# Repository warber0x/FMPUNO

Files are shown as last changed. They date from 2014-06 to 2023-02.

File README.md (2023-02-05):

# Finally FMPUNO Is now compatible with python3 :gift:
- Nickname in arduino forum: BlackSharp (to search through the arduino forum discussion)
- Date of the first release: 12/24/2013.
- Date of last release: 24/11/2021
- Date Github publish: 06/05/2014.
- Video link: https://www.youtube.com/watch?v=Dh3tBewMzdY

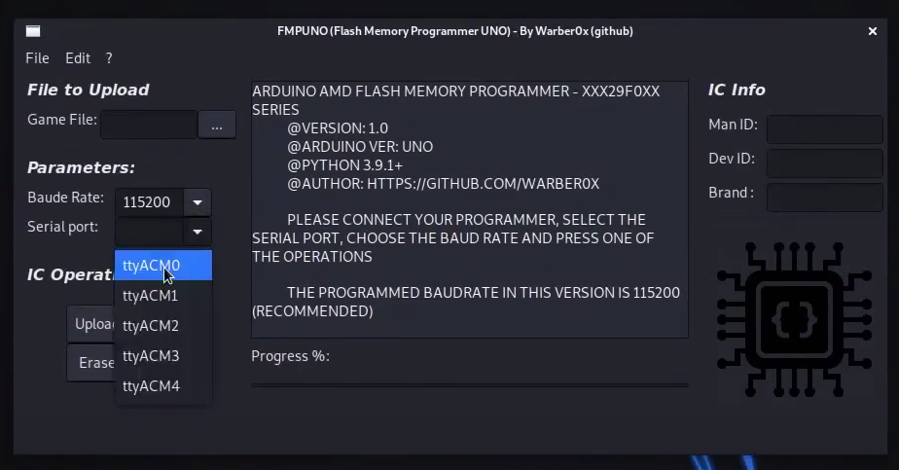
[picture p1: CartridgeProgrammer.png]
Cartridge Programmer


After so many years, I wanted to bring to life this project that I made before and make it more stable especially the GUI app. Now, the application is more stable and works like a charm.

**IMPORTANT NOTICE: The diagram wiring image has an issue**
* PIN 32 -> VCC
* PIN 16 -> Ground

## Introduction:
This project is a Flash memory programmer based on Arduino UNO.

The main reason for creating this project is to be able to program a flash memory, put it in gameboy cartidge and play any game you want. The commercial programmer is expensive and creating your own is fun ...

In this repo you'll find the graphic scheme of the project in JPEG format as well as in Fritzing format.

If you wan to build this, it's not difficult. Just respect the wiring and everything will be okay. 

The diagram is not perfect I know but it helps ... Maybe one day I will make it better :zzz:

Some resistors are not added in the diagram. Therefore, don't forget to add resistor for every input especially for Adresses and Data chip pins, the same for arduino and the shift registers (The floating state values is the main problem if it doesn't work). All of the resistors in the project are in 10Kohms.

You must have a gameboy cartidge that has a flash instead of ROM chip

Adding to this, I have programmed a Python GUI software to make a chip programming more easier. The supported chips are:

- Amic A29040.
- AMD AM29F040.
- AMD AM29F010.

The GUI app works with python3. It crashes sometimes when the upload is finished. You are free to increase or customize the code (But keep my name plz).

## REQUIREMENTS: 💾
- Computer with linux/Windows 7. Linux is recommanded (I was testing on KALI)
- Tested with python3 (There were major bugs in python2)
- Wxpython library (pip3 install wxpython)
- Pubsub lib 
- Arduino IDE with the Flash_memory_programmer Sketch.
- Circuit, Diagram ... you know what I mean :wink:
- Chip AM29F010-40, A29010-40

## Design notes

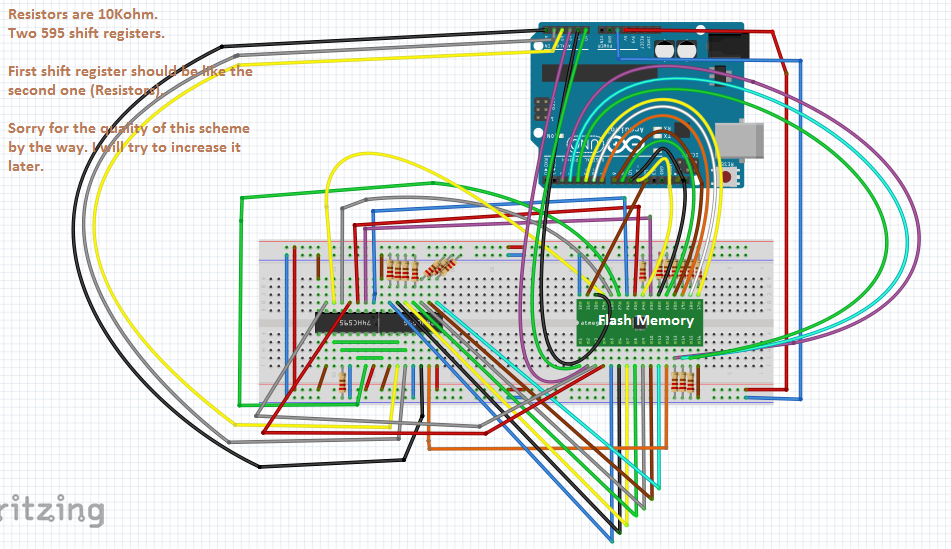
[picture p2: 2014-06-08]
Schemes/Scheme Flash Memory Programmer.png

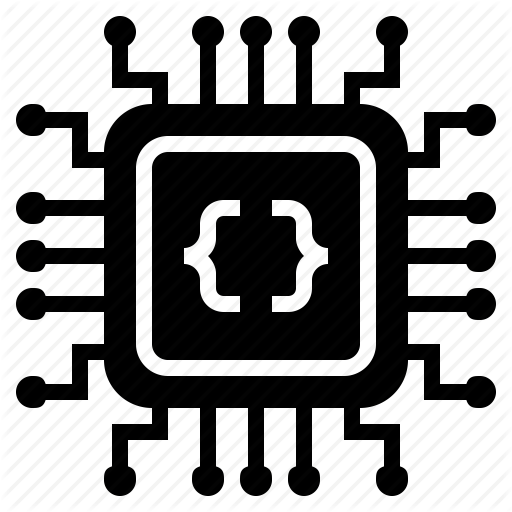
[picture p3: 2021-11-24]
GUI_python3/avr.png

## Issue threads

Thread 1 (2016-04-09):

Wire on pin 16 going into ground, not vcc

bogger33, 2016-04-09:
Hey, thanks for the project!

The wiring diagram has a mistake in it, the wire from pin 16 of the chip is red, but goes into ground on the diagram, and so does the one on pin 32 (which is blue). Pin 32 should go to vcc

warber0x, 2016-04-11:
Thanks dude. Good looking out.

Closed 2018-01-28.

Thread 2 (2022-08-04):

Issue with running the python GUI

gufunkt-tacos, 2022-08-04:
Whenever I try to run the code it outputs this error.

`C:\Users\Administrator\Downloads\FMPUNO-master\FMPUNO-master\GUI_python3>python FlashMemoryProgrammer_GUI.py
Traceback (most recent call last):
  File "C:\Users\Administrator\Downloads\FMPUNO-master\FMPUNO-master\GUI_python3\FlashMemoryProgrammer_GUI.py", line 852, in <module>
    thread1 = starter(1, 'Thread-1', 1)
  File "C:\Users\Administrator\Downloads\FMPUNO-master\FMPUNO-master\GUI_python3\FlashMemoryProgrammer_GUI.py", line 840, in __init__
    frame = programmer_gui(parent=None, id=-1)
  File "C:\Users\Administrator\Downloads\FMPUNO-master\FMPUNO-master\GUI_python3\FlashMemoryProgrammer_GUI.py", line 93, in __init__
    font3 = wx.Font(12, wx.NORMAL, wx.ITALIC, wx.BOLD)
wx._core.wxAssertionError: C++ assertion ""ff_family != (0<<4)"" failed at ..\..\src\msw\font.cpp(624) in wxNativeFontInfo::SetFamily(): unknown wxFontFamily`

I've installed PubSub and wxPython. My python version is 3.9.1 and I have the same error with 3.9.13.

TheR3d0ne, 2022-08-04:
@gufunkt-tacos check this out [https://stackoverflow.com/questions/5278884/fonts-problem-when-switching-from-wxpython-2-8-to-2-9](https://stackoverflow.com/questions/5278884/fonts-problem-when-switching-from-wxpython-2-8-to-2-9). It's
 a wxPython version problem. Otherwise, you can modify the code to be aligned with your version.

Closed 2022-08-07.

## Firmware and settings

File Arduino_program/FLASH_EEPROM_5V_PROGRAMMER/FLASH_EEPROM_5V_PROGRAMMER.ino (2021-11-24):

/* @Author: Radouane SAMIR
   @Version: 0.1
   @Chip version: AM29F010 A29040
   
   This code is tested on AM29F010.
   
   For AM29F040B the command sequence are little bit different:
   0x555 rather than 0x5555 see the datasheet. But the timing is the same
   
   You are free to modify the code as you want, but please keep my name as is.
*/

#include <avr/io.h>
#include <util/delay.h>

/* Flash SIZE, used only in read operation*/
#define FLASHSIZE 131072 

uint32_t address = 0;
uint32_t gameSize = 0;

char buffer[20] = {0};
char cmd = 0;
int  index = 0;
char tab[10] = {0};

/* Need a fast change mode IN/OUT */

void flash_change_pins_mode(boolean io)
{
  if (io) {
    DDRD &= ~(1<<2);
    DDRD &= ~(1<<3);
    DDRD &= ~(1<<4);
    DDRD &= ~(1<<5);
    DDRD &= ~(1<<6);
    DDRD &= ~(1<<7);
    DDRB &= ~(1<<0);
    DDRB &= ~(1<<1);
  }
  else
  {
    DDRD |= (1<<2);
    DDRD |= (1<<3);
    DDRD |= (1<<4);
    DDRD |= (1<<5);
    DDRD |= (1<<6);
    DDRD |= (1<<7);
    DDRB |= (1<<0);
    DDRB |= (1<<1);
  }
}

void flash_ctrl_deselect()
{
  digitalWrite(10, HIGH);  //CE
  digitalWrite(12, HIGH);  //WE
  digitalWrite(11, HIGH);  //OE
}

void flash_ctrl_rd()
{
  digitalWrite(11, LOW);
  _delay_us(1);
  digitalWrite(10, LOW);
  _delay_us(1);
}

void flash_ctrl_wr()
{
  digitalWrite(10, LOW);
  _delay_us(1);
  digitalWrite(12, LOW);
  _delay_us(1);
}  

/**************************************************
   Function to access to 
   the highest addresses in the chip 
   Highest 16bits is given to the function
   and do a bit manipulation to set pins High/Low
***************************************************/

void flash_set_highest_addresses(uint16_t addr)
{ 
  /* Highest addresses */
  
  if (addr&bit(0))
  PORTC |= _BV(PORTC2);
  else
  PORTC &= ~_BV(PORTC2);
  
  if (addr&bit(1))
  PORTC |= _BV(PORTC1);
  else
  PORTC &= ~_BV(PORTC1);
  
  if (addr&bit(2))
  PORTC |= _BV(PORTC0);
  else
  PORTC &= ~_BV(PORTC0);
}

/****
 * Shift registers manipulation
 *******************************/

void flash_enable_latch()
{
  /* Shift register Latch */
  digitalWrite(A4, HIGH); 
}

void flash_disable_latch()
{
  /* Shift register Latch */
  digitalWrite(A4, LOW);
}

void flash_enable_serial_clock()
{
  /* Shift register Serial clock */
  digitalWrite(A3, HIGH);
}

void flash_disable_serial_clock()
{
  digitalWrite(A3, LOW);
}

/** 
 * Calculated the given address
 * shift register manipulation
 **************************************/ 

void flash_send_serial_data(uint16_t data)
{ 
  /* Shift register manipulation */
  /* Respect the wiring */
  
  uint16_t addr = 0;
  byte octect1 = 0; 
  byte octect2 = 0;
  
  addr = (data<<8);
  octect1 = (addr>>8);
  
  addr = (data>>8);
  octect2 = addr;
  
  flash_disable_latch();
  for (int i=7;i>=0; i--)
  {
    flash_disable_serial_clock();
    if (octect2&(1<<i))
    PORTC |= _BV(PORTC5);
    else
    PORTC &= ~_BV(PORTC5);
    flash_enable_serial_clock();
  }
  
  
  for (int i=7;i>=0; i--)
  {
    flash_disable_serial_clock();
    if (octect1&(1<<i))
    PORTC |= _BV(PORTC5);
    else
    PORTC &= ~_BV(PORTC5);
    flash_enable_serial_clock();
  }
  flash_enable_latch();
}

/**
 * Set the address *
 *******************/

void flash_addr_set(uint32_t addr)
{
  /* Send address  to the shift register  */
  
  uint16_t LSB;
  uint16_t MSB;
  
  LSB = addr;
  MSB = (addr>>16);
  
  flash_send_serial_data(LSB);
  flash_set_highest_addresses(MSB);
}

/**
 * Calculate the data given and set change pins state
 *****************************************************/

void flash_data_set(uint8_t data)
{
  uint8_t temp;
  uint8_t temp2;
  
  temp = (data<<2);
  temp2 = (data>>6);
  
  for (int i = 2; i < 8; i++)
  {
    if (temp&bit(i))
    {
      DDRD |= (1<<i);
      PORTD |= (1<<i);
    }
    else
    {
      PORTD &= ~(1<<i);
      DDRD &= ~(1<<i);  
    }
   
  }
  
  if(temp2&(1<<0)) 
  {
    DDRB |= _BV(PORTB0);
    PORTB |= _BV(PORTB0);
  }
  else
  {
    PORTB &= ~_BV(PORTB0);
    DDRB &= ~(1<<0);
  }
  
  if(temp2&(1<<1))
  {
    DDRB |= _BV(PORTB1);
    PORTB |= _BV(PORTB1);
  }
  else
  {
    PORTB &= ~_BV(PORTB1);
    DDRB &= ~_BV(PORTB1);
  }
}

/** 
 * Get Data from the chip *
 * MIND: the pull-down resistors
 *********************************/

byte flash_data_get()
{
  /* get data from data bus */
  
  byte data = 0;
  boolean state = LOW;
  boolean state2 = LOW;
  
  for (int i = 2, j = 0; i <= 9; i++, j++)
  {
        state = digitalRead(i);  
        state2 = digitalRead(i); 
        if (state == state2)
           if (state == HIGH)
           bitWrite(data, j, HIGH); 
           
  }
  return data;
}

/*
 * Data polling in programming operation
 *****************************************/

boolean flash_DQ7_byte_poll(uint32_t addr, byte data)
{
  byte octect = 0;
  flash_change_pins_mode(1);
  flash_addr_set(addr);
  flash_ctrl_rd();
  octect = (flash_data_get()>>7);
  while (octect!=(data>>7));
  flash_ctrl_deselect();
  return true;
}

boolean flash_DQ7_erase_poll()
{
  byte octect = 0;
  flash_change_pins_mode(1);
  octect = (flash_data_get()>>7);
  
  while (octect!=1)
  octect = (flash_data_get()>>7);
  
  if (octect)
  Serial.println("Erasure complete");
  
  flash_ctrl_deselect();
  return true;
}

/****
 * Set command sequence and send it to the chip
 ***********************************************/

void flash_send_command(uint32_t addr, uint8_t data)
{
  /* Send command sequence */
  
  flash_addr_set(addr);
  delayMicroseconds(1);
  flash_ctrl_wr();

  flash_data_set(data);
  delayMicroseconds(1);
}

/****
 * Autoselect mode to get info from the chip
 * It's useful to test the chip before any operation
 ******************************************************/

void flash_device_id()
{
  /* This is used to get code identification 
   * from the chip in autoselect mode
   * See the datasheet
   ******************************************/
  
  flash_ctrl_deselect();
  
  //digitalWrite(11, HIGH);
  
  delay(1000);
  
  flash_change_pins_mode(0);
  
  flash_send_command(0x5555, 0xAA);
  flash_ctrl_deselect();
  
  
  flash_send_command(0x2AAA, 0x55);
  flash_ctrl_deselect();
  
  flash_send_command(0x5555, 0x90);
  flash_ctrl_deselect();
 
  delay(1000);
  
  flash_change_pins_mode(1);

  flash_addr_set(0x01);
  delay(1);
  flash_ctrl_rd();
  
  Serial.print(flash_data_get(), HEX);
  //Serial.print("Get device ID complete, Please wait restarting the chip ... ");
  delay(1);
  flash_reset_chip();
  //Serial.println("Done.");
  delay(1000);
  flash_ctrl_deselect();
}

/** AM29F040 **/
/***************/

void flash_get_id_40()
{
  /* This is used to get code identification 
   * from the chip in autoselect mode
   * See the datasheet
   ******************************************/
   
  byte data = 0x00;
  
  flash_ctrl_deselect();
  
  //digitalWrite(11, HIGH);
  
  delay(1000);
  
  flash_change_pins_mode(0);
  
  flash_send_command(0x555, 0xAA);
  flash_ctrl_deselect();
  
  flash_send_command(0x2AA, 0x55);
  flash_ctrl_deselect();
  
  flash_send_command(0x555, 0x90);
  flash_ctrl_deselect();
 
  delay(1000);
  
  flash_change_pins_mode(1);

  flash_addr_set(0x00);
  flash_ctrl_rd();
  
  data = flash_data_get();
  
  if (data < 0x0A) 
  Serial.print("0");
  
  Serial.print(data, HEX);
  
  flash_ctrl_deselect();
  
  flash_reset_chip();
  delay(1000);
}


void flash_get_id()
{
  /* This is used to get code identification 
   * from the chip in autoselect mode
   * See the datasheet
   ******************************************/
   
  byte data = 0x00;
  
  flash_ctrl_deselect();
  
  //digitalWrite(11, HIGH);
  
  delay(1000);
  
  flash_change_pins_mode(0);
  
  flash_send_command(0x5555, 0xAA);
  flash_ctrl_deselect();
  
  flash_send_command(0x2AAA, 0x55);
  flash_ctrl_deselect();
  
  flash_send_command(0x5555, 0x90);
  flash_ctrl_deselect();
 
  delay(1000);
  
  flash_change_pins_mode(1);
  
  flash_addr_set(0x00);
  flash_ctrl_rd();
  
  data = flash_data_get();
  
  if (data < 0x0A) 
  Serial.print("0");
  
  Serial.print(data, HEX);
  
  flash_ctrl_deselect();
  
  flash_reset_chip();
  delay(1000);
}

void flash_read_memory(uint32_t addr)
{
  /* Read the chip until the address given */  
  int c = 0;
  
  flash_change_pins_mode(1);
  
  for (uint32_t i = 0; i < addr; i++)
  {
    flash_ctrl_deselect();
    
    flash_addr_set(i);
    
    flash_ctrl_rd();
    
    Serial.print(flash_data_get(),HEX); 
    flash_ctrl_deselect();
  }
}

/* This is the sequence to program a byte on the memory *
 * 0x5555 0x2AAA is for AM29F010
 * 0x555 0x2AA is for AM29F040 A29F040
 ********************************************************/

boolean flash_program_byte(uint32_t addr, uint8_t data)
{
  flash_ctrl_deselect();
  
  flash_send_command(0x5555, 0xAA); 
  flash_ctrl_deselect();
  
  flash_send_command(0x2AAA, 0x55);
  flash_ctrl_deselect();
  
  flash_send_command(0x5555, 0xA0);
  flash_ctrl_deselect();
  
  //Program Address & Program data
  flash_send_command(addr, data);
  flash_ctrl_deselect();
  
  /** Data Polling **/
  while (!flash_DQ7_byte_poll(addr, data));
  
  return true;
}

/* This is the sequence to program a byte on the memory *
 * 0x5555 0x2AAA is for AM29F010
 * 0x555 0x2AA is for AM29F040 A29F040
 ********************************************************/

void flash_reset_chip()
{
  /* This is reset command for the AM29F010 */
  
  flash_ctrl_deselect();
  
  flash_send_command(0x5555, 0xAA);
  flash_ctrl_deselect();
  
  flash_send_command(0x2AAA, 0x55);
  flash_ctrl_deselect();
  
  flash_send_command(0x5555, 0xF0);
  flash_ctrl_deselect();
  
  delay(1000);
}

/* This is the sequence to program a byte on the memory *
 * 0x5555 0x2AAA is for AM29F010
 * 0x555 0x2AA is for AM29F040 A29F040
 ********************************************************/

void flash_erase_memory()
{
  flash_ctrl_deselect();
  delay(1000);
  
  //flash_change_pins_mode(0);
  
  flash_send_command(0x5555, 0xAA);
  flash_ctrl_deselect();
  
  flash_send_command(0x2AAA, 0x55);
  flash_ctrl_deselect();
  
  flash_send_command(0x5555, 0x80);
  flash_ctrl_deselect();
  
  flash_send_command(0x5555, 0xAA);
  flash_ctrl_deselect();
  
  flash_send_command(0x2AAA, 0x55);
  flash_ctrl_deselect();
  
  flash_send_command(0x5555, 0x10);
  flash_ctrl_deselect();
  
  _delay_ms(1000);
  //flash_DQ7_erase_poll();
  flash_reset_chip();
  Serial.print("Erasure Complete");
}

/* To erase AM29F040 */
/*********************/

void flash_erase_memory2()
{
  flash_ctrl_deselect();
  delay(1000);
  
  //flash_change_pins_mode(0);
  
  flash_send_command(0x555, 0xAA);
  flash_ctrl_deselect();
  
  flash_send_command(0x2AA, 0x55);
  flash_ctrl_deselect();
  
  flash_send_command(0x555, 0x80);
  flash_ctrl_deselect();
  
  flash_send_command(0x555, 0xAA);
  flash_ctrl_deselect();
  
  flash_send_command(0x2AA, 0x55);
  flash_ctrl_deselect();
  
  flash_send_command(0x555, 0x10);
  flash_ctrl_deselect();
  
  _delay_ms(1000);
  //flash_DQ7_erase_poll();
  //flash_reset_chip();
  Serial.print("Erasure Complete");
}

/*
 * Read data coming from the computer's USB port *
 *************************************************/

void receiveDataFromPC()
{
  if (Serial.available()>0)
  {
    uint8_t data = Serial.read();
    flash_program_byte(address++, data); 
  }
}

/* Intiate the programing when the python GUI send a trigger */
/*************************************************************/

void startProgramming()
{
    flash_change_pins_mode(0);
    
    Serial.print("+");
    while (!Serial.available());
    while (Serial.available() > 0)
    {
      char car = Serial.read();
      delay(10);
      tab[index++]=car;
      
    }
    tab[index] = '\0';
    
    Serial.print("+");
    
    while(address <= atol(tab)) {
    receiveDataFromPC();
    }
}

void setup()
{
  Serial.begin(115200);
  //ANALOG_CONFIG;
  
  int c = 0;
 
  //Set the shift register pins
  
  pinMode(A5, OUTPUT);
  pinMode(A4, OUTPUT);
  pinMode(A3, OUTPUT);
  
  //set the highest address pins
  
  pinMode(A2, OUTPUT);
  pinMode(A1, OUTPUT);
  pinMode(A0, OUTPUT);
  
  //Set the chip controller
  
  pinMode(10, OUTPUT);
  pinMode(11, OUTPUT);
  pinMode(12, OUTPUT);
  
  //Set data pin mode
  pinMode(2, OUTPUT);
  pinMode(3, OUTPUT);
  pinMode(4, OUTPUT);
  pinMode(5, OUTPUT);
  pinMode(6, OUTPUT);
  pinMode(7, OUTPUT);
  pinMode(8, OUTPUT);
  pinMode(9, OUTPUT);
  
  delay(1000);
  
  address = 0;
  
  flash_ctrl_deselect();
}

void loop()
{ 
  while (!Serial.available());
  cmd = Serial.read();
  
  switch(cmd)
  {
    case 'R':
    flash_read_memory(0xFF);
    Serial.println("");
    break;
    
    case 'E':
    flash_erase_memory();
    Serial.println("");
    break;
    
    case 'W':
    startProgramming();
    Serial.println("");
    break;
    
    case 'I':
    flash_get_id();
    Serial.println("");
    break;
    
    case 'D':
    flash_device_id();
    Serial.println("");
    break;
  
    default:
    cmd = 0;
  }
  cmd = 0;
  index = 0;
  memset(tab, '\0', sizeof(tab));
  delay(10);
}

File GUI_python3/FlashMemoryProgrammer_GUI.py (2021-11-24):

#!/usr/bin/python
# -*- coding: utf-8 -*-

# @Author of this software: Warber0x.
# @Date: 26/12/2021
# @Version: 1.0 Beta
# @Baud rate: Check the arduino Sketch

# THIS NEEDS A WXPYTHON TO BE EXECUTED.
# Systel used Kali 2020
# Python version 3

# This is the latest version that's compatible with python 3

import wx
import os
import sys
import time
import serial
import struct
import _thread
import threading
import binascii
import ctypes
import time

from wx.lib.buttons import GenBitmapTextButton
from pubsub import pub


class programmer_gui(wx.Frame):
    gauge_counter = 0
    def __init__(self, parent, id):

        wx.Frame.__init__(
            self,
            parent,
            id,
            'FMPUNO (Flash Memory Programmer UNO) - By Warber0x (github)'
                ,
            size=(900, 450),
            style=wx.DEFAULT_FRAME_STYLE ^ wx.RESIZE_BORDER
                ^ wx.MAXIMIZE_BOX ^ wx.MINIMIZE_BOX,
            )

        panel = wx.Panel(self, pos=(0, 100), size=(700, 200))
        self.percent = 0

        img = wx.Image('./avr.png')
        img.Rescale(170, 170)
        png = wx.Bitmap(img)
        wx.StaticBitmap(panel, -1, png, (713, 170), (png.GetWidth(),
                        png.GetHeight()))

        # Menu Gui

        status = self.CreateStatusBar()

        menubar = wx.MenuBar()
        filemenu = wx.Menu()
        editmenu = wx.Menu()
        aboutmenu = wx.Menu()

        exititem = filemenu.Append(wx.NewIdRef(), '&Exit', '')
        aboutitem = aboutmenu.Append(wx.NewIdRef(), '&About',' Information about this program')
        edititem1 = editmenu.Append(wx.NewIdRef(), '&Read', '')
        edititem2 = editmenu.Append(wx.NewIdRef(), '&Erase', '')
        edititem3 = editmenu.Append(wx.NewIdRef(), '&Program', '')

        menubar.Append(filemenu, 'File')
        menubar.Append(editmenu, 'Edit')
        menubar.Append(aboutmenu, '?')

        self.SetMenuBar(menubar)
        self.Bind(wx.EVT_MENU, self.OnAbout, aboutitem)
        self.Bind(wx.EVT_MENU, self.OnExit, exititem)
        self.Bind(wx.EVT_MENU, self.OnRead, edititem1)
        self.Bind(wx.EVT_MENU, self.OnErase, edititem2)
        self.Bind(wx.EVT_MENU, self.OnProgram, edititem3)

        # End menubar

        # imageFile = "write.png"
        # imageFile2 = "read.png"
        # imageFile3 = "erase.png"
        # imageFile4 = "info.png"

        # imageWrite = wx.Image(imageFile, wx.BITMAP_TYPE_ANY).ConvertToBitmap()
        # imageRead = wx.Image(imageFile2, wx.BITMAP_TYPE_ANY).ConvertToBitmap()
        # imageErase = wx.Image(imageFile3, wx.BITMAP_TYPE_ANY).ConvertToBitmap()
        # imageInfo = wx.Image(imageFile4, wx.BITMAP_TYPE_ANY).ConvertToBitmap()

        font3 = wx.Font(12, wx.NORMAL, wx.ITALIC, wx.BOLD)
        label6 = wx.StaticText(panel, -1, 'IC Operations:', (10, 200), size=(200, -1))
        label6.SetFont(font3)

        self.buttonProgram = wx.Button(panel, id=-1, label='Upload', pos=(50, 240), size=(65, 40))
        self.buttonRead = wx.Button(panel, id=-1, label='Read',  pos=(50 + 65, 240), size=(65, 40))
        self.buttonErase = wx.Button(panel, id=-1, label='Erase',pos=(50, 280), size=(65, 40))
        self.buttonInfo = wx.Button(panel, id=-1, label='Infos', pos=(50 + 65, 280), size=(65, 40))

        self.textarea = wx.TextCtrl(panel, pos=(240, 10), style=wx.TE_MULTILINE | wx.TE_READONLY, size=(450, 265))

        font1 = wx.Font(12, wx.NORMAL, wx.ITALIC, wx.BOLD)
        label1 = wx.StaticText(panel, -1, 'File to Upload', (10, 10), size=(200, -1))
        label1.SetFont(font1)

        label4 = wx.StaticText(panel, -1, 'Game File: ', (10, 40))
        self.uploadText = wx.TextCtrl(panel, -1, pos=(85, 40), size=(100, -1), style=wx.TE_READONLY)
        buttonDlg = wx.Button(panel, id=-1, label='...', pos=(185,40), size=(40, 30))

        self.ln = wx.StaticLine(panel, -1, pos=(20, 80), size=(200,-1), style=wx.LI_HORIZONTAL)

        font1 = wx.Font(12, wx.NORMAL, wx.ITALIC, wx.BOLD)
        label1 = wx.StaticText(panel, -1, 'Parameters:', (10, 90), size=(200, -1))
        label1.SetFont(font1)

        label3 = wx.StaticText(panel, -1, 'Baude Rate: ', (10, 120), size=(200, -1))
        baude = [
            '115200',
            '57600',
            '38400',
            '28800',
            '19200',
            '14400',
            '9600',
            '4800',
            ]
        self.baudBox = wx.ComboBox(panel,-1,pos=(100, 120),size=(100, -1),choices=baude,style=wx.CB_READONLY,)

        label5 = wx.StaticText(panel, -1, 'Serial port: ', (10, 150), size=(200, -1))
        arduinoSerial = ['ttyACM0', 'ttyACM1', 'ttyACM2', 'ttyACM3', 'ttyACM4']
        self.serialBox = wx.ComboBox(panel,-1,pos=(100, 150),size=(100, -1),choices=arduinoSerial,style=wx.CB_READONLY,)

        self.ln = wx.StaticLine(panel, -1, pos=(20, 190), size=(200, 1), style=wx.LI_HORIZONTAL)

        gaugeText = wx.StaticText(panel, -1, 'Progress %: ', (240, 283))
        self.gauge = wx.Gauge(panel, -1, 100, pos=(240, 300), size=(450, 25))

        # create a pubsub listener
        pub.subscribe(self.updateProgress, "update")

        font6 = wx.Font(12, wx.NORMAL, wx.ITALIC, wx.BOLD)
        label6 = wx.StaticText(panel, -1, 'IC Info', (710, 10), size=(200, -1))
        label6.SetFont(font6)

        label7 = wx.StaticText(panel, -1, 'Man ID: ', (710, 45))
        self.manid = wx.TextCtrl(panel, -1, pos=(770, 45), size=(120,
                                 -1), style=wx.TE_READONLY)

        label8 = wx.StaticText(panel, -1, 'Dev ID: ', (710, 80))
        self.devid = wx.TextCtrl(panel, -1, pos=(770, 80), size=(120,
                                 -1), style=wx.TE_READONLY)

        label2 = wx.StaticText(panel, -1, 'Brand : ', (710, 115))
        chip = ['AM29F010', 'AM29F040']
        self.flashref = wx.TextCtrl(panel, -1, pos=(770, 115), size=(120,
                                    -1), style=wx.TE_READONLY)

        self.ln = wx.StaticLine(panel, -1, pos=(700, 150), size=(200,
                                -1), style=wx.LI_HORIZONTAL)

        self.Bind(wx.EVT_BUTTON, self.OnProgram, self.buttonProgram)
        self.Bind(wx.EVT_BUTTON, self.OnDlg, buttonDlg)
        self.Bind(wx.EVT_BUTTON, self.OnRead, self.buttonRead)
        self.Bind(wx.EVT_BUTTON, self.OnErase, self.buttonErase)
        self.Bind(wx.EVT_BUTTON, self.OnInfos, self.buttonInfo)
        self.Bind(wx.EVT_CLOSE, self.OnExit)

        self.intro = \
            '''ARDUINO AMD FLASH MEMORY PROGRAMMER - XXX29F0XX Series
            @Version: 1.0
            @Arduino ver: UNO
            @Python 3.9.1+
            @Author: https://github.com/warber0x

            Please connect your programmer, select the serial port, choose the baud rate and press one of the operations

            The programmed baudrate in this version is 115200 (Recommended)

            '''
        self.intro = self.intro.upper()
        self.textarea.SetValue(self.intro)

        self.count = 0
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

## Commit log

2014-06-08 Flash Memory Programmer
    [Scheme.fzz]
2014-06-08 Arduino Sketch
